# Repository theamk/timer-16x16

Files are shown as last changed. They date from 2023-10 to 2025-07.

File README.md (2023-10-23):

Timer with 16x16 dot display
----------------------------

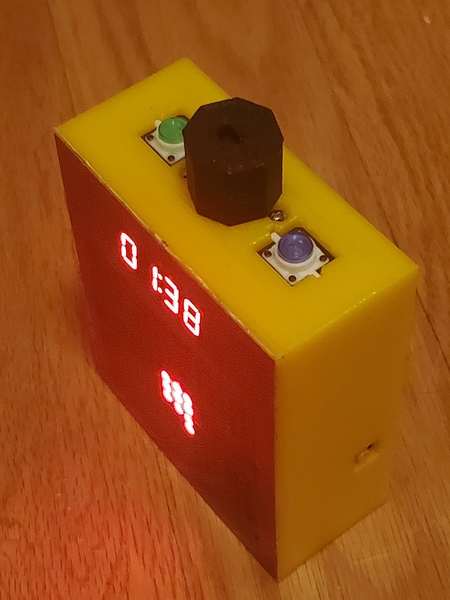
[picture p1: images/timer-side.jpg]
side view


Parts used
----------

The links are to aliexpress and things often disappear there.. so you might need to shop based on the pictures.
Also, I mostly used parts I had on hand already, hence so many different sellers. If buying all the parts for
this project, get similar looking ones from one seller.

- Raspberry PI PICO (non-W version,
  get one from your [local hardware store](https://www.microcenter.com/product/661033/raspberry-pi-pico-microcontroller-development-board))
- 4x 8x8 dot displays, based on MAX7219 chipset. You want the ones which can be stacked next to each other, with no protruding parts.
  I used red ones from my parts box. [Those](https://www.aliexpress.us/item/3256805799080954.html) look the same.
- 1x 0.36" 4-digit LED indicator, driven by TM1637. I used red one from my parts box, but it looks like 
  [this one](https://www.aliexpress.us/item/3256804119383891.html).
    - Had to desolder headers and attach wires directly instead.
- Input panel:
    - 2x buttons with LEDs (blue and green), "12x12" type ([those](https://www.aliexpress.us/item/2255799843768811.html)) 
    - Rotary encoder from my parts box.
    - Small piece of PCB to mount this all on. I've had [2x8cm proto PCB](https://www.aliexpress.us/item/3256804759687459.html) I've cut in half.
    - Pull-up resistors (I found 10x 2.2K resistor array in my toolbox)
- 3d-printed case, see [3dprint/] directory.
    - There are 3 parts: main body, holder for displays (goes between PCB and display itself) and encoder knob.
- Protoboard PCB, 70x90 mm ([this one](https://www.aliexpress.us/item/2251832485396886.html), but others would work too. 
  Note the dimensions vary a bit, especially in hole placement. You might need to tweak 3D model for your speciic board).
- 3D printed case
- Some colored film to cover the front - this is supposed to increase contrast. 
  I had red film in my parts box, no idea where I got it from)
- Optional: speaker
    - Small speaker (piezo or 4-ohm one)
    - almost any transistor (I had 2N222 in my parts box)
    - a resistor for that transistor
- Optional: battery setup (see below for details)

Schematics
----------

Sorry, never made a schematics. There is a PCB which serves as a back cover and as a mechanical
support, but most wiring is point-to-point. Here is a pinout:
```
Pinout:
  (left side)
  GP0
  GP1

  GP2
  GP3
  GP4
  GP5

  GP6   O - speaker (active high, via 2N2222 transistor)
  GP7
  GP8  IO - POSSIBLE EXPANSION: IMU SDA  (w/2.2K pull-up)
  GP9  IO - POSSIBLE EXPANSION: IMU SCL  (w/2.2K pull-up)

  GP10  I - encoder A (w/2.2K pull-up)
  GP11  I - encoder B (w/2.2K pull-up)
  GP12  I - button green (w/2.2K pull-up)
  GP13  I - button blue (w/2.2K pull-up)

  GP14  O - LED green (270 ohm to GND, active high)
  GP15  O - LED blue (270 ohm to GND, active high)

  (right side)
  GP16  I - SPI RX (unused)
  GP17  O - SPI CSn to MAX7219 8x8 displays

  GP18  O - SPI SCK to MAX7219 8x8 displays
  GP19  O - SPI TX to MAX7219 8x8 displays
  GP20  O - DATA to TM1637
  GP21  O - CLK to TM1637

  GP22  O - set high to force power off
  GP23  I - on-board voltage regulator mode selector
  GP24  I - on-board USB voltage sensor
  GP25  O - on-board LED

  GP26
  GP27
  GP28
```

PCB, mostly point-to-point wiring, the only moderately complex system is power

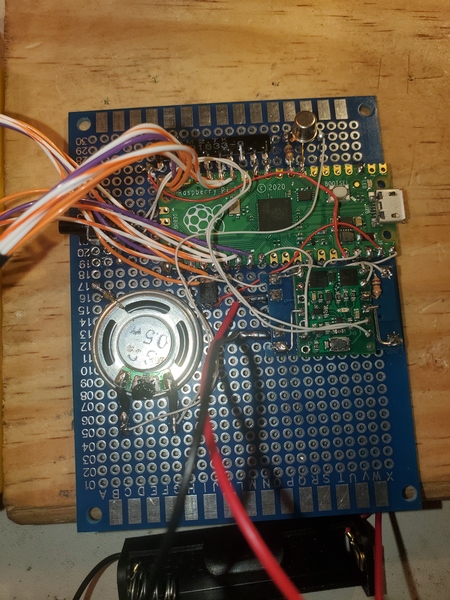
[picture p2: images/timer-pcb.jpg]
PCB (rear cover) view


The other side - enclosure with buttons and LEDs

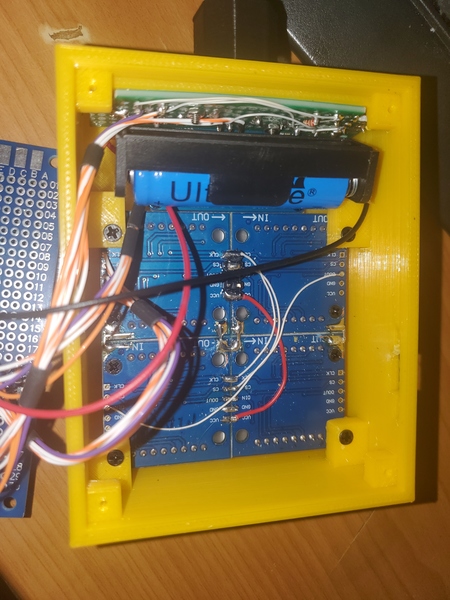
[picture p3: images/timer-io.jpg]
LED + buttons view


Mechanical assembly
-------------------

See 3d-printed case, see [3dprint/] directory.
There are 3 parts: main body, holder for displays (goes between PCB and display itself) and encoder knob.

For 8x8 displays, I've used some thick wires to solder the groundplanes together, making a single 16x16 panel. 
This turned out to be not the best idea in retrospect - I've got flatness wrong so you can see (and feel) boundaries 
between modules. A better idea would be to 3D print holders and mount each one using default mounting holes.

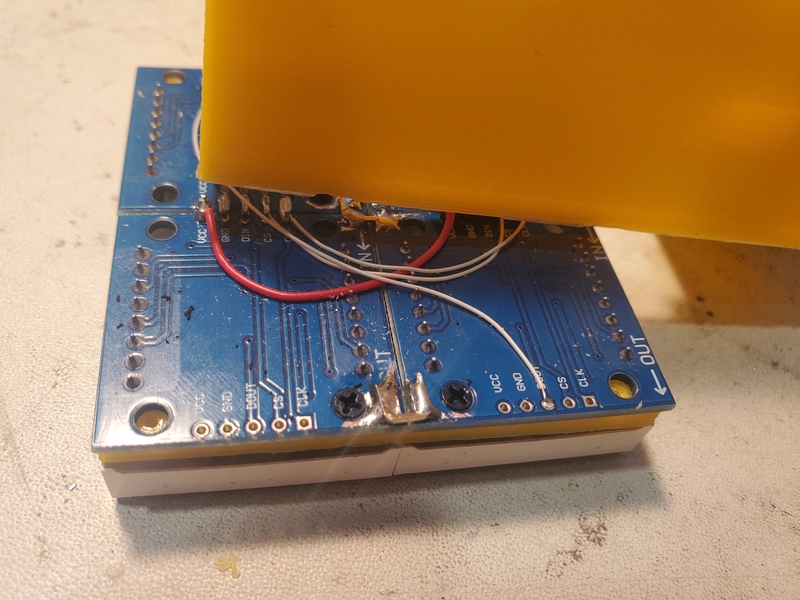
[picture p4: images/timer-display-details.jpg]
mounting displays


Power control
-------------

For simpler design, feel free to skip. Connect Vin pins of display to 
pico's VSYS, and you have a USB-powered device.

Or get [Pimoroni's lipo SHIM](https://shop.pimoroni.com/products/pico-lipo-shim?variant=32369543086163), 
I have not tried it but specs look good.. seems like it basically does all I do here in one tiny board.
Just needs a transistor across the power button to allow soft power off (and a very minor case redesign,
as "USB" and "Power" would be just one hole now).

I wanted rechargable battery, so I went with:

- Battery itself: AA holder + 14500 3.7V Li-ion battery
    - Be wary of that a lot 14500 Li-ion batteries are apparently very low quality - one I got had 130 mAh capacity instead of rated 1800 mAh.
    - Alternatively, 18650 with tabs might fit and be both cheaper and more powerful
- Battery charger board (
    [Micro USB 5V 1A 18650 TP4056 Lithium Battery Charger Module Charging Board With Protection](https://www.aliexpress.us/item/2251832640561273.html))
- Power switch board (to enable soft power off). I used [Pololu Mini Pushbutton Power Switch](https://www.pololu.com/product/2808)
    - This turned out to be too easy to turn off by accident. I wonder if [Sparkfun's Soft Power Switch](https://www.sparkfun.com/products/17870),
      which requires power button to be held for a long time to turn off, would work better?
        - It would also allow eliminating separate power button entirely, allowing one of the two big buttons on top to act as power switch.
- Power on/off button (right-angle tactile switch)

Charger/protection board is generic TP4056 model
It came with 1A charge current, but I modified it to ~500mA current:
The current is set by resistor labeled R3.
The stock R3 was 122, which is 1.2K, which is ~1A.
I replaced it with 2201, which means 2.2K, which gave me ~0.56A limit.

Note that LEDs draw directly from battery, so the actual charging current is less
when display is on. Current use:

- pixels brightness 1: 80 to 240 mA, depending on # of pixeles lit
- pixels brightness 7: not measured, probably too bright

The overall schematics is somewhat complicated, because Pico and LEDs
have different power paths. This was because of requirements:

1. When powering from battery, give as much voltage to LEDs as possible, 
avoiding any diode drops (they are officially rated for 5V only after all, and I am powering
them from 3.6V lithium battery.. let's not make it worse).
2. Fully support operation when powered from pico's USB port.
3. Have "soft" power switch, with recessed button and software-controlled power-off. It should
   work even over USB.

```
 PICO:VBUS               GND
   |                      |
[ VIN+                   VIN- ]
[                             ]
[ charger / protection board  ]
[ (upside-down to expose LED) ]
[ modded to decrease Icharge  ]
[                             ]
[  OUT+ BATT+    BATT-  OUT-  ]
    |    |         |     |
    |    \- 14300 -/    GND
    |
    |              /-PICO:GP22
  /---\   /-GND-\  |  x   x
  |   |   |     |  |  |   |
[ IN+ IN+ GND GND ON OFF CTRL ]
[                             ]
[  POLOLU mini pushshbutton   ]
[   power switch (LV 2808)    ]
[                             ]
[ OUT OUT GND GND  SW-A  SW-B ]
   |   |  |     |    |     |
   \-|-/  \-GND-/    \-BTN-/    <- power button (outside)
     |
     +---PICO:3V3_EN   (so switch works even for USB input)
     +--[R:10K]--GND   (making sure 3V3_EN is pulled down with output is off)
     +--Vcc of LED displays
     |
     \--|>|--PICO:VSYS (use any diode, PI has regulator that'll step voltage up if needed)
```

Firmware
--------

1. Install [platformio](https://platformio.org/install). I use "core" version which is a simple command line tool.

2. Power up the device and plug in USB cable

3. `pio run -t upload`

4. If building for the very first time, it may fail because there is no bootloader in the image. In this case:

    - Power up/plug in device while holding "prog" button on the Pico board
    - Your computer should detect an removable disk dialog
    - The "pio run" error message should have mentioned an UF2 file location..
       Usually something like `.pio/build/pico/firmware.uf2`.
    - Copy this file to external disk. Device will auto-reboot into new firmware.
    - This only needs to be done once, once firmware is in place regular upload should just work..

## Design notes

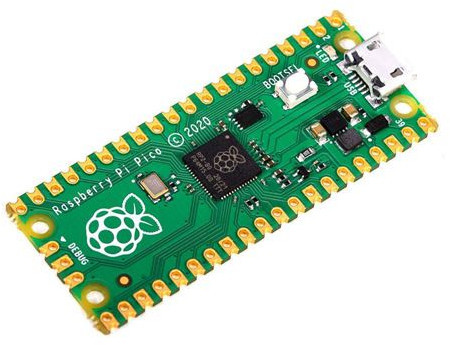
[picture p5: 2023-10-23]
images/pi-pico.jpg

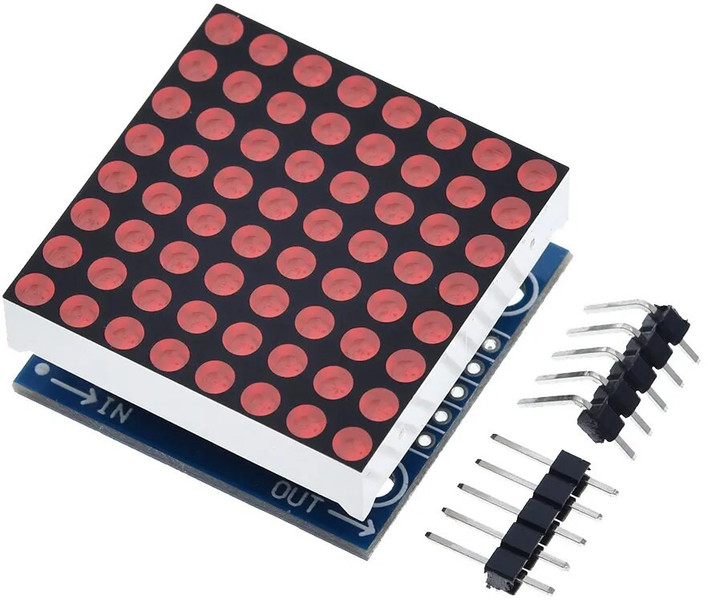
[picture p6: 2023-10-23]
images/display-8x8.jpg

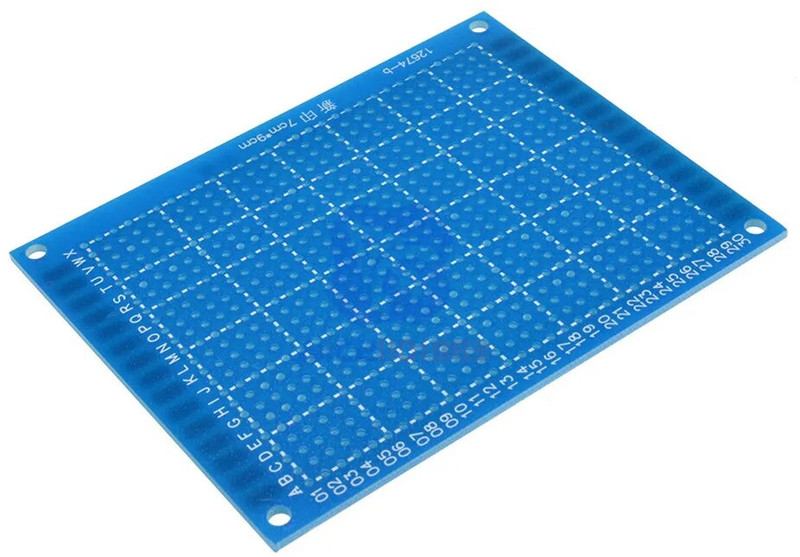
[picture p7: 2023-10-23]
images/PCB-7x9.jpg

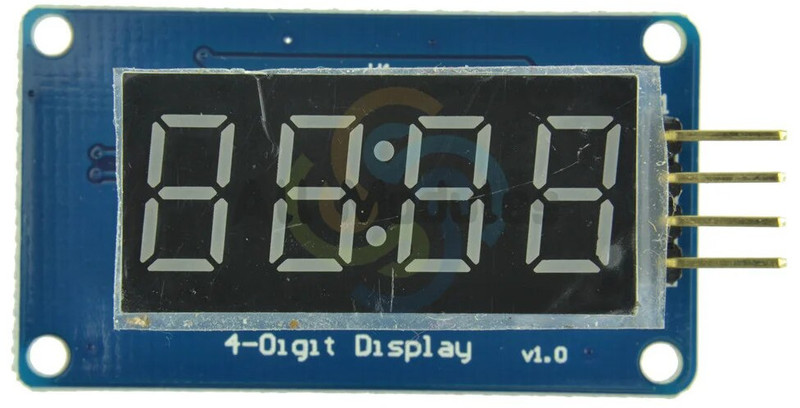
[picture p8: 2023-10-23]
images/display-7seg.jpg

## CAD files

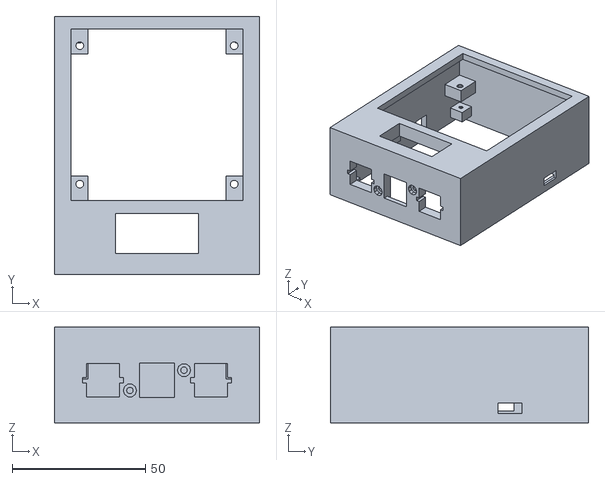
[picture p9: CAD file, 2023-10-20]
3dprint/timer16x16box.stl
77.0 x 97.0 x 36.0

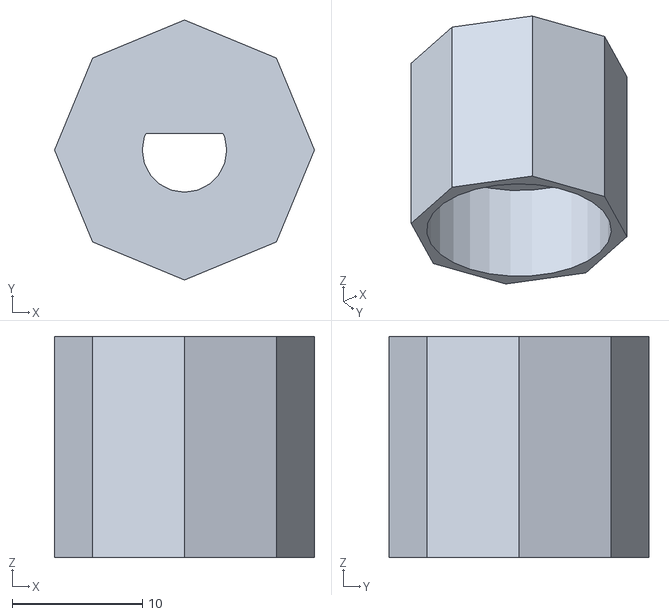
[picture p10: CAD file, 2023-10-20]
3dprint/knob-d-shaft-1.stl
20.0 x 20.0 x 17.0

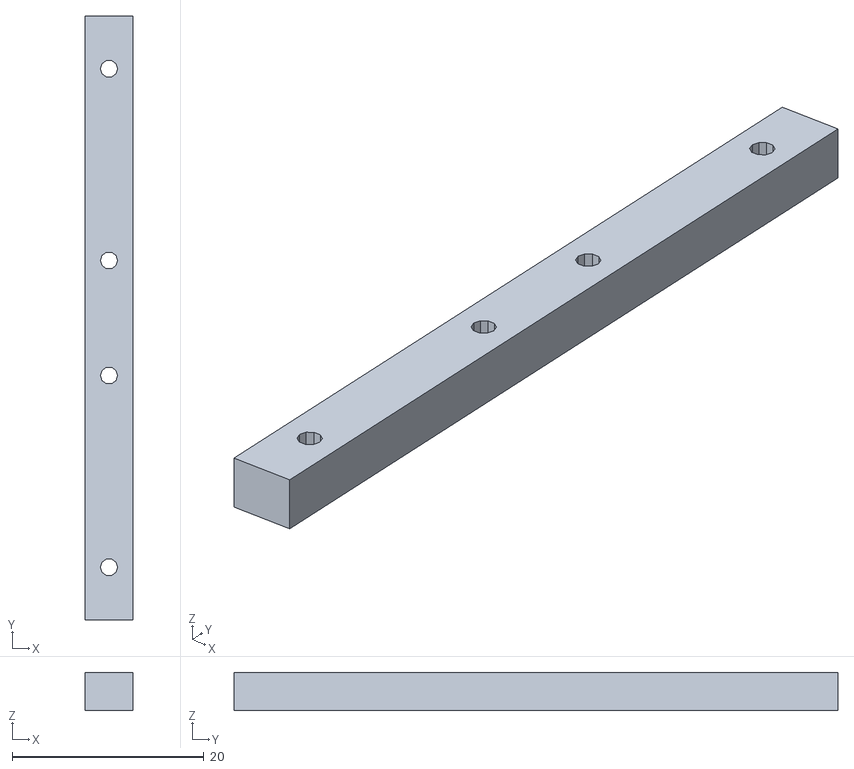
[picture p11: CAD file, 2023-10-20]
3dprint/timer16x16holder.stl
5.00 x 63.0 x 4.00

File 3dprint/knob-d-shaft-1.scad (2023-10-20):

// a knob for unnamed encoder
// with D-shaped 6 mm shaft

SHAFT_D = 6 + 0.5; // diameter
// height of part at the end with flat
SHAFT_CUTOUT_HEIGHT = 8; 
// flat diameter (to ther end of shaft, as measured by calipers)
SHAFT_CUTOUT_DEPTH = 4.5; 

KNOB_D = 20;
KNOB_INNER_D = 17; // hide encoder body
KNOB_HEIGHT = 17; // including TOP_WALL

TOP_WALL = -0.1; 

difference() {
    // knob body, intentionally non-circular
    cylinder(d=KNOB_D, h=KNOB_HEIGHT, $fn=8);
    
    // at the bottom, there is a wide cutout
    translate([0, 0, -0.1])
    cylinder(d=KNOB_INNER_D, h=KNOB_HEIGHT - SHAFT_CUTOUT_HEIGHT - TOP_WALL + 0.1);
    
    difference() {
        // shaft hole
        cylinder(d=SHAFT_D, h=KNOB_HEIGHT - TOP_WALL, $fn=20);
        
        // "D" cutout
        translate([-10, SHAFT_CUTOUT_DEPTH - SHAFT_D/2, 0])
        cube([20, 20, 40]);
    }
}

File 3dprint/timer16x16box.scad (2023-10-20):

// box for 16x16 timer
//  top side (closed) is where displays are
//  bottom side is closed with lid, made out of PCB

// rev 2 ("yellow") comments:
//  - Printed with 10mm brim, "high detail" mode. This was very slow,
//    but came out great.
//  - 256PX hole supports were so thick I had to switch to 12mm screws
//    which I only have in 2.6 mm dia.. so had to drill out the holes
//  - power button hole wrong (too tall) - not a real problem
//  - USB hole wrong (shifted by 1mm) - had to file it
//  - both power button and USB connection stick out of board.. so any time
//    board is installed/removed, there is a pressure on power button. 
//    It works so far, but I suspect button might fail eventually
//  - 7-segment display was a bit tricky to install due to control board
//    extra base overhanging.. but managed eventually. Maybe shorten
//    that extra base a bit.
//  - cutting corners of controls board was a pain. Maybe reduce size of PCB
//    mounting block?

WALL = 3;

// "Lip" on top, to conceal sides of red film
// walls are reduced thickness, as they are not structural
// NOTE: lip sounded like a great idea but my printer can't print it
// at h=1. So setting it to almost 0 to disable
LIP_HEIGHT = 0.001; 
LIP_WALL = 3;

// bottom lip height. walls are full thickness
// (this is offset from PCB mounting blocks to bottom of the box,
// if this is = to PCB thickness, the bottom would be even)
BOTTOM_LIP_HEIGHT = 3;

// inner X/Y is defined by PCB size, which is used as a bottom cover
INNER_X = 70 + 1; // don't forget some slop
INNER_Y = 90 + 1;
INNER_Z = 30;

// PCB mounting block hole offset from board edge
PCB_HOLE_X1 = 3.5;
PCB_HOLE_X2 = 2.5;
PCB_HOLE_Y = 3.5;
PCB_BLOCK_Z = 5;  // mounting block Z thickness
PCB_BLOCK_XY = 7; // mounting block X/Y extra 

// 7-segment (for time)
// mounting PCB is non-symmetric, but we don't bother to mode it fully,
// and instead increase sizes so that both sides fit, assuming display is centered
// (real one is smaller on one side)
PCB_Y_7SEG = 25; // height of PCB, _if_ it were symmetric
PCB_X_7SEG = 45; // width of PCB, _if_ it were symmetric
// center Y, Z offset
OFFSET_Y_7SEG = PCB_Y_7SEG / 2 - 0.1;
// top of PCB to top of display
HEIGHT_7SEG = 7.5;

// no overlap with Y- wall (except tiny one to avoid rounding errors)
assert((OFFSET_Y_7SEG - PCB_Y_7SEG/2) >= -0.1);

// 16x16 module, made out of quad 8x8
SIZE_256PX = 64; // module is square
SLOP_256PX = 0.5; // evenly spread across both sizes
THICKNESS_256PX = 13.5; // front panel to back of PCB
OFFSET_Y_256PX = INNER_Y - SIZE_256PX / 2 - 2; // Y of centerpoint of display
MNT_256PX_X_OFFS = 3; // hole offset X, from side
MNT_256PX_Y_OFFS = 6; // hole offset Y, from side
MNT_256PX_SIZE = 6;  // Y axis is twice as much

// overlap with 7-segment display is not too big (small one is OK)
assert((OFFSET_Y_7SEG + PCB_Y_7SEG/2 - 8) <= 
       (OFFSET_Y_256PX - SIZE_256PX/2));

CONTROLS_CENTER_Z = INNER_Z / 2 + 2; // slightly shifted to front
       
// Charger hole, size - need to fit "most" usb cables,
// and there is a power switch underneath too
CHARGER_HOLE_SIZE_Y = 9;
CHARGER_HOLE_SIZE_Z = 4;
CHARGER_HOLE_PCB_Y = 21;
CHARGER_HOLE_PCB_Z = 2;
// and center offset
CHARGER_HOLE_OFFSET_Y = 26.5; // PCB side to center of hole
CHARGER_HOLE_OFFSET_Z = 0.5; // PCB inner surface to bottomhole
       
// power switch - which is 7x7 button with right angle mount
POWER_HOLE_SIZE_Y = 8;
POWER_HOLE_SIZE_Z = 8;
// and center offset
POWER_HOLE_OFFSET_Y = 29; // PCB side to center of switch
POWER_HOLE_OFFSET_Z = 1.5; // PCB inner surface to bottom of button hole

/*
// battery box (which is a single AA holder with 14500 lipo inside)
// (bare battery: 53x14x14, holder: 59x17x17)
BBOX_SIZE_X = INNER_X + 0.1;
BBOX_SIZE_Y = 14;
BBOX_SIZE_Z = 14;
BBOX_WALL = 2;
*/
     
difference() {   
    // outer walls
    // Zmin = INNER_Z + BOTOMLIP_HEIGHT
    // Zmax = WALL + LIP_HEIGHT
    translate([-WALL, -WALL, -INNER_Z - BOTTOM_LIP_HEIGHT])
    cube([INNER_X + 2*WALL, INNER_Y + 2*WALL, 
          INNER_Z + WALL + BOTTOM_LIP_HEIGHT + LIP_HEIGHT]);
    
    difference() {
        // main volume for PCB
        translate([0, 0, -(INNER_Z + 100) - 0.1])
        cube([INNER_X, INNER_Y, INNER_Z + 100]);
        
        // extra base for 7-segment digits
        translate([INNER_X / 2, OFFSET_Y_7SEG, 0])
        cube([PCB_X_7SEG, PCB_Y_7SEG, HEIGHT_7SEG], center=true);
        
        // extra base control buttons backplane 
        translate([INNER_X / 2 - 65/2, -0.1, -CONTROLS_CENTER_Z - 20/2])
        cube([65, 2, 20]);

        /*
        // battery box
        translate([INNER_X / 2 - BBOX_SIZE_X / 2 - BBOX_WALL, 
                   INNER_Y - BBOX_SIZE_Y - BBOX_WALL - 0.1,
                   -INNER_Z])
        cube([BBOX_SIZE_X + BBOX_WALL * 2, 
              BBOX_SIZE_Y + BBOX_WALL, 
              BBOX_SIZE_Z + BBOX_WALL]);
        */
    }

    /*
    // battery box cutout
    translate([INNER_X / 2 - BBOX_SIZE_X / 2, 
               INNER_Y - BBOX_SIZE_Y,
               -INNER_Z - 0.1])
    cube([BBOX_SIZE_X, BBOX_SIZE_Y, BBOX_SIZE_Z + 0.1]);
    */

    // Top lip cutout
    translate([LIP_WALL-WALL, LIP_WALL-WALL, WALL])
    cube([INNER_X - 2*(LIP_WALL-WALL), INNER_Y - 2*(LIP_WALL-WALL), 100]);
        
    // cutout for 256PX (16x16) display
    translate([INNER_X / 2, OFFSET_Y_256PX, 0])
    cube([SIZE_256PX + SLOP_256PX, SIZE_256PX + SLOP_256PX, THICKNESS_256PX],
         center=true);
    
    // cutout for 7-segment digits
    // (we don't bother with mouting holes, they are drilled in place)
    translate([INNER_X / 2, OFFSET_Y_7SEG, 0])
    cube([31, 15, 100], center=true);
    
    /*
    // cutout for encoder, 25LB10Q model
    translate([INNER_X / 2, 1, -INNER_Z / 2])
    rotate([90, 0, 0]) {
        cylinder(d=8.5, h=10);  // main shft
        // anti-rotatino hole
        translate([0, -10, 0]) cylinder(d=4, h=10);
        // body - a slight dip (note contacts are 2 more mm)        
        cube([22, 22, 4], center=true);        
    }
    */
    
    // cutout for encoder, unnamed PCB-mount model
    translate([INNER_X / 2, 1, -CONTROLS_CENTER_Z]) {
        // main body
        cube([13, 20, 13], center=true);
        // expand top/bottom side for contacts
        cube([13, 3.5, 17], center=true);
    }
    
    // cutout for control buttons
    for (ox=[-1, 1])
    translate([INNER_X / 2 + ox * 8 * 2.54, 1, -CONTROLS_CENTER_Z]) {
        cube([12.5, 10, 12.5], center=true);
        // extra for light connectors
        cube([15.5, 10, 2], center=true);
    }
    
    // holes for control panel mount
    for (ox=[-1, 1])
    translate([INNER_X / 2 + ox * 4 * 2.54, 
                1, 
                -CONTROLS_CENTER_Z + ox * 1.5 * 2.54])
        rotate([90, 0, 0]) {
        // hole
        cylinder(d=2.5, h=30, center=true, $fn=10);
        // concealed head
        translate([0, 0, WALL - 1])
        cylinder(d=5, h=10, $fn=10);
        }
            
           
    // cutout for power button - a latching, lighted model
    //translate([INNER_X * 0.75, INNER_Y - 1, -INNER_Z / 2])
    //rotate([-90, 0, 0])
    //cylinder(d=12, h=10);
    
    // port for USB connection
    translate([INNER_X - 1,
               INNER_Y - CHARGER_HOLE_OFFSET_Y - CHARGER_HOLE_SIZE_Y / 2, 
               -INNER_Z + CHARGER_HOLE_OFFSET_Z])
    cube([10, CHARGER_HOLE_SIZE_Y, CHARGER_HOLE_SIZE_Z]);
    
    // a small cutout for PCB that USB connector is mounted on
    translate([INNER_X - 0.1,
               INNER_Y - CHARGER_HOLE_OFFSET_Y - CHARGER_HOLE_PCB_Y / 2, 
               -INNER_Z])
    cube([WALL - 1, CHARGER_HOLE_PCB_Y, CHARGER_HOLE_PCB_Z]);
    
    translate([-10,
               INNER_Y - POWER_HOLE_OFFSET_Y - POWER_HOLE_SIZE_Y/2, 
               -INNER_Z + POWER_HOLE_OFFSET_Z])
    cube([20, POWER_HOLE_SIZE_Y, POWER_HOLE_SIZE_Z]);
}

// 256PX mounting blocks
mount_block_hole_x = (INNER_X - SIZE_256PX) / 2 + MNT_256PX_X_OFFS;
for (ox=[-1, 1]) for (oy=[-1, 1])
    translate([INNER_X/2 - ox * INNER_X / 2, 
               oy * (SIZE_256PX - 2*MNT_256PX_Y_OFFS) / 2 + OFFSET_Y_256PX, 
               -THICKNESS_256PX - WALL])
    scale([ox, oy, 1])
    difference() {
        translate([-0.1, 
                   -(MNT_256PX_SIZE + 0.2)/2, 
                   0])
        cube([mount_block_hole_x + MNT_256PX_SIZE / 2 + 0.1, 
              2 * MNT_256PX_SIZE+0.2, 
              MNT_256PX_SIZE]);
        
        translate([mount_block_hole_x, 0, -1])
        cylinder(d=3, h=30, $fn=10);
}
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

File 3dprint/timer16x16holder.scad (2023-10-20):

// a holder to mount256px display
// print 2 of those, insert between display and PCB
// works together with "timer16x16box" model


// from timer16x16box.scad
SIZE_256PX = 64; // module is square
MNT_256PX_Y_OFFS = 6; // hole offset Y, from side

// defined here
SLOP = 1;
WIDTH = 5;
THICKNESS = 4;

difference() {
    cube([WIDTH, SIZE_256PX - SLOP, THICKNESS], center=true);
    for (oy=[-1, 1]) 
      scale([1, oy, 1]) {
        // two holes in the middle are attaching holder to display
        // they are for making install easier only
        translate([0, MNT_256PX_Y_OFFS, 0])
        cylinder(d=1.8, h=10, center=true, $fn=10);
        
        // two holes in the sides are important ones, they accept
        // mounting screws
        translate([0, SIZE_256PX/2 - MNT_256PX_Y_OFFS, 0])
        cylinder(d=1.8, h=10, center=true, $fn=10);
    }
}    

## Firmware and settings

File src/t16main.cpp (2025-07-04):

/*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
You should have received a copy of the GNU General Public License along with
this program. If not, see <https://www.gnu.org/licenses/>.
*/
#include <Arduino.h>

#include <stdlib.h>
//#include <pico/rand.h>
#include <include/lwipstack/lwipopts.h>

#include <RP2040_PWM.h>
#include "TM1637.h"
#include <pio_encoder.h>

#include "display_driver.h"

/*

Future hardware:
   accelerometer
*/

void set_random_pixels(int count);

#define CLOCK_CLK    21
#define CLOCK_DIO    20
TM1637 clock_disp(CLOCK_CLK, CLOCK_DIO);


#define PIN_LED_GREEN   15
#define PIN_LED_BLUE    14
#define PIN_BTN_GREEN   13
#define PIN_BTN_BLUE    12

#define PIN_ENCODER_A   10
#define PIN_ENCODER_B   11

#define PIN_POWER_OFF   22

#define PIN_SPEAKER     6

// how long to spend in settings mode with no input before switching off
#define IDLE_POWER_OFF_INTERVAL  (10 * 60 * 1000)

// How many ms of shaking does each encoder turn add?
#define SHAKE_MS_PER_ENCODER_TICK    100
// What's the maximum wind-up?
#define SHAKE_MS_MAX_VALUE           3000
// How many MS per shake state (on ouptut)
#define SHAKE_MS_PER_STATE           50

PioEncoder encoder(PIN_ENCODER_A);  // B must be A + 1
RP2040_PWM * speaker;

unsigned long power_off_time = 0;
int shake_amount_ms = 0;

void setup() {
  pinMode(LED_BUILTIN, OUTPUT);

  pinMode(PIN_LED_GREEN, OUTPUT);
  pinMode(PIN_LED_BLUE, OUTPUT);

  encoder.begin();

  clock_disp.begin();
  clock_disp.clearScreen();

  display_init();

  srand(lwip_get_random());

  speaker = new RP2040_PWM(PIN_SPEAKER, 1000, 0);

  //set_random_pixels(60);

}

void set_random_pixels(int count) {
  if (count > 255) { count = 255; };
  display_set_all(false);
  while (count > 0) {
    int x = random() % DISP_WIDTH;
    int y = random() % DISP_HEIGHT;
    if (!display_setpixel(x, y, true)) { count--; };
  }

  display_update();
}

void set_spiral_pixels(int count, int shake=0) {
  display_set_all(false);
  int x=0, y=0;
  int dx=0, dy=-1;
  int shake_x=0, shake_y=0;

  static const int shake_offsets[8][2] = {
    {-1, 1}, {0, 1}, {1, 1}, {1, 0},  {1, -1}, {0, -1}, {-1, -1}, {-1, 0},  //{-1, 1}
  };
  if (shake > 0) {
    // Since shaking lasts for a short time, we make no attempt to compensate when many LEDs are lit
    // total number of lit leds might be <count if shake is nonzero
    int mult  = ((shake - 1)) / 32 + 1;
    int phase = ((shake - 1)) % 8;
    shake_x = shake_offsets[phase][0] * mult;
    shake_y = shake_offsets[phase][1] * mult;
  }

  while (count > 0) {
    display_setpixel(x + 7 + shake_x, y + 7 + shake_y, true);
    if ((x == y) || (x < 0 && x == -y) || (x > 0 && x == 1 - y)) {
      int temp = dx;
      dx = -dy;
      dy = temp;
    }
    x += dx; y += dy;
    count--;
  }
  display_update();
}


int last_speaker_freq = -1;
void set_speaker_freq(int freq) {
  if (last_speaker_freq == freq) {
    return;
  }
  if (freq == 0) {
    speaker->setPWM(PIN_SPEAKER, 1000, 0);
  } else {
    // very low duty cycle.. "10" (10%) is enough to be pretty loud.
    speaker->setPWM(PIN_SPEAKER, freq, 5);
  }
  last_speaker_freq = freq;
}


enum {
  T_TICK_UP,
  T_TICK_DOWN,
  T_EXPIRED,
  T_SET_TIME,
} timer_mode = T_SET_TIME;

enum {
  M_EXIT,     // default, exit menu
  M_SET_STEP, // set time interval
  // set end tone
  // set display type (spiral/random/etc...)
  M_MAX_VALUE = M_SET_STEP,
} menu_item = M_EXIT;
bool menu_active = false;

// timer value, seconds
int time_left = 0;
// millis() timestamp when this changes
unsigned long next_tick = 0;
// how many seconds does each pixel represent
int pixel_time = 10;


unsigned long tone_state = 0;
void maybe_update_speaker() {
  if (!tone_state) {
    set_speaker_freq(0);
  } else { // play the tone
    unsigned int elapsed = millis() - tone_state;
    static int melody[] = {
      523, 523, 587, 523, 698, 659,
    };

    if ((elapsed % 300) < 50) { set_speaker_freq(0); }
    else {
      unsigned int num = elapsed / 300;
      if (num < (sizeof(melody)/sizeof(melody[0]))) {
	set_speaker_freq(melody[num]);
      } else {
	tone_state = 0;
	set_speaker_freq(0);
      };
    }
  }
}


void handle_buttons() {
  // debounce green
  static unsigned long green_down_since = 0;
  bool green_down = false;
  if (digitalRead(PIN_BTN_GREEN)) {
    green_down_since = 0;
  } else if (!green_down_since) {
    green_down_since = millis();
  } else if (millis() > (green_down_since + 50)) {
    green_down = true;
  }

  static unsigned long blue_down_since = 0;
  bool blue_down = false;
  if (digitalRead(PIN_BTN_BLUE)) {
    blue_down_since = 0;
  } else if (!blue_down_since) {
    blue_down_since = millis();
  } else if (millis() > (blue_down_since + 50)) {
    blue_down = true;
  }

  static bool green_was_down = false;
  if (green_down && !green_was_down) {
    // green button controls timer mode
    if (menu_active) {
      // exit menu
      menu_active = false;
    } else switch(timer_mode) {
      case T_EXPIRED:
      case T_TICK_UP:
      case T_TICK_DOWN: // was ticking -> pause, set time
	timer_mode = T_SET_TIME;
	break;
      case T_SET_TIME:
	if (time_left == 0) {
	  timer_mode = T_TICK_UP;
	} else {
	  timer_mode = T_TICK_DOWN;
	}
	next_tick = millis();
	break;
      }
  };
  green_was_down = green_down;

  static bool blue_was_down = false;
  if (blue_down && !blue_was_down) {
    // blue button enters menu, then executes menu item
    if (!menu_active) {
      // enter menu
      menu_active = true;
    } else switch (menu_item) {
      case M_EXIT:
	menu_active = false;
	break;
      case M_SET_STEP:
	// TODO
	break;
    }
  };
  blue_was_down = blue_down;

  if (green_down || blue_down) {
    power_off_time = 0; // any input resets power-off timer
    tone_state = 0; // any input turns tone off
  }
}


void handle_encoder() {
  // our encoder gives us 4 counts per detent
  int this_encoder = encoder.getCount() / 4;
  static int last_encoder = 0;
  int delta_encoder = this_encoder - last_encoder;
  last_encoder = this_encoder;

  if (delta_encoder == 0) {
    return;
  }
  power_off_time = 0;
  tone_state = 0; // any input turns tone off

  if (menu_active) {
    (int&)menu_item = ((int)menu_item + delta_encoder + M_MAX_VALUE + 1) % (M_MAX_VALUE + 1);
  } else if (timer_mode == T_SET_TIME) {
    // when pixels are small, always do one step == one pixel. But when they are large, provide finer steps.
    int scroll_step = (pixel_time < 60) ? pixel_time :
      (time_left >= 600) ? 60 : 15;
    while (delta_encoder < 0) {
      delta_encoder++;
      time_left = ((time_left - 1) / scroll_step) * scroll_step;
      if (time_left < 0) { time_left = 0; }
    }
    while (delta_encoder > 0) {
      delta_encoder--;
      time_left = ((time_left / scroll_step) + 1) * scroll_step;
    }
  } else {
    // shake it!
    shake_amount_ms += SHAKE_MS_PER_ENCODER_TICK * delta_encoder;
    if (shake_amount_ms > SHAKE_MS_MAX_VALUE) { shake_amount_ms = SHAKE_MS_MAX_VALUE; }
    if (shake_amount_ms < -SHAKE_MS_MAX_VALUE) { shake_amount_ms = -SHAKE_MS_MAX_VALUE; }
  }
}


void update_leds() {
  unsigned long partial = (millis() + 2000 - next_tick) % 1000;
  switch (timer_mode) {
  case T_TICK_UP:
  case T_TICK_DOWN:
    digitalWrite(PIN_LED_GREEN, partial < 100); // blink  once per second
    break;
  case T_EXPIRED:
    digitalWrite(PIN_LED_GREEN, (partial % 250) < 125); // blink quickly nonstop
    break;
  case T_SET_TIME:
    digitalWrite(PIN_LED_GREEN, true);
  }

  digitalWrite(PIN_LED_BLUE, menu_active);
}


void update_maybe_power_off() {
  if (timer_mode == T_TICK_UP || timer_mode == T_TICK_DOWN) {
    // if timer is ticking or inputs, don't power off
    power_off_time = 0;
  } else if (!power_off_time) {
    // activity happened, reset timer
    power_off_time = millis() + IDLE_POWER_OFF_INTERVAL;
  } else if (power_off_time < millis()) {
    // power off time
    digitalWrite(PIN_POWER_OFF, 1);
    // should not reach here, but in case it didn't work for some reason, reset.
    delay(100);
    digitalWrite(PIN_POWER_OFF, 0);
    power_off_time = 0;
  }
}


#include "generated_images.inc"

const int kPixelTimeOptions[] = { 10, 15, 30, 60, 120 };
#define kPixelTimeOptionCount (sizeof(kPixelTimeOptions)/sizeof(kPixelTimeOptions[0]))

void maybe_refresh_256px_display() {
  uint16_t* icon = NULL;

  if (menu_active) {
    switch (menu_item) {
    case M_EXIT:
      static_assert(MiscIcons_COUNT > 0);
      icon = MiscIcons[0];
      break;
    case M_SET_STEP:
      static_assert(StepSet_COUNT == kPixelTimeOptionCount);
      for (int i=0; i<StepSet_COUNT; i++) {
	if (kPixelTimeOptions[i] == pixel_time) {
	  icon = StepSet[i];
	  break;
	}
      }
      if (!icon) {
	// error/undefined value -> blink two options to indicate this
	icon = ((millis() / 100) % 2) ? StepSet[0] : StepSet[StepSet_COUNT-1];
      }
      break;
    }
  }
  
  static uint16_t* last_icon = nullptr;
  static int last_pixels = -1, last_shake_state = -1;

  if (icon) {
    if (icon != last_icon) {
      display_show_icon(icon);
      display_update();
      last_icon = icon;
    }
    last_pixels = -1;
    return;
  }
  last_icon = nullptr;

  int pixels = (time_left + pixel_time - 1) / pixel_time;

  if (timer_mode == T_TICK_DOWN && ((time_left % pixel_time) == 1)) {
    // last pixel blinks before disappearing
    unsigned long partial = 1000 - (millis() + 2000 - next_tick) % 1000;
    if ((partial > 50 && partial < 100) ||
	(partial > 150 && partial < 200)) {
      pixels--;
    }
  };

  int shake_state = abs(shake_amount_ms) / SHAKE_MS_PER_STATE;

  if (pixels != last_pixels || shake_state != last_shake_state) {
    set_spiral_pixels(pixels, shake_state);
    last_pixels = pixels;
    last_shake_state = shake_state;
  };
}

void maybe_refresh_7seg_display() {
  char buff[20] = {};
  if (time_left < 3600) {
    // less than 1 hour -> show minutes + seconds, 2 digits
    sprintf(buff, "%02d%02d", (time_left / 60), (time_left % 60));
  } else {
    // more than 1 hour -> show hours + minutes, 1 digit
    sprintf(buff, "%2d%02d", (time_left / 3600), ((time_left / 60)% 60));
  }
  if (timer_mode == T_SET_TIME && power_off_time) {
    // blink on idle input
    unsigned long idle = (millis()  + IDLE_POWER_OFF_INTERVAL - power_off_time );
    if ((idle > 500) & ((idle % 500) > 250)) {
      sprintf(buff, "      ");
    }
  }
  bool colon = (timer_mode != T_TICK_UP) || (timer_mode != T_TICK_DOWN) || (time_left & 1);

  // Force change invisible character because there is a bug: display won't refresh if
  // only colon changes but string stays the same.
  buff[4] = colon ? ':' : ' ';
  buff[5] = 0;

  static String last_display = "ZZZZZZ";
  if (last_display == buff) {
    return;
  }
  last_display = String(buff);

  // Re-enable pins if they were disabled before (see below)
  pinMode(CLOCK_DIO, OUTPUT);
  pinMode(CLOCK_CLK, OUTPUT);
  delay(1);

  clock_disp.setBrightness(7); // 0..7
  if (colon) {
    clock_disp.colonOn();
  } else {
      clock_disp.colonOff();
  }
  clock_disp.display(last_display);

  // We want to tri-state control pins between runs, to enable soft shut-off
  // the TM1637 library we have uses "mI2C.h" driver, which uses regular digitalWrite
  // calls. So we can just tri-state the pins.
  pinMode(CLOCK_CLK, INPUT_PULLUP);
  pinMode(CLOCK_DIO, INPUT);
}


void loop() {
  handle_buttons();
  handle_encoder();

  update_leds();
  maybe_update_speaker();

  unsigned long now = millis();
  static unsigned long prev_now;
  if (shake_amount_ms > 0) {
    shake_amount_ms = max(0, shake_amount_ms - (int)(now - prev_now));
  } else if (shake_amount_ms < 0) {
    shake_amount_ms = min(0, shake_amount_ms + (int)(now - prev_now));
  }
  prev_now = now;

  // tick handling
  switch (timer_mode) {
  case T_SET_TIME:
  case T_EXPIRED:
    break;
  case T_TICK_UP:
  case T_TICK_DOWN:
    if (next_tick < millis()) {
      next_tick += 1000;
      if (timer_mode == T_TICK_UP) {
	time_left++;
      } else {
	time_left--;
	if (time_left == 0) {
	  timer_mode = T_EXPIRED;
	  tone_state = millis(); // start music playback
	}
      }
    }
    break;
  }

  update_maybe_power_off();

  maybe_refresh_7seg_display();
  maybe_refresh_256px_display();
}

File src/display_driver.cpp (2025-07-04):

#include <display_driver.h>
#include <Arduino.h>

#include <SPI.h>

SPISettings display_settings(100000, MSBFIRST, SPI_MODE0);
#define SPI1_MISO 16  // not used
#define SPI1_MOSI 19
#define SPI1_SCLK 18
#define SPI1_CS_DISP 17
//arduino::MbedSPI SPI1(SPI1_MISO, SPI1_MOSI, SPI1_SCLK);

static void display_send_raw(uint8_t cmd, uint8_t data[4]) {
  digitalWrite(SPI1_CS_DISP, 0);
  SPI.beginTransaction(display_settings);
  delay(1);
  SPI.transfer(cmd); SPI.transfer(data[0]);
  SPI.transfer(cmd); SPI.transfer(data[1]);
  SPI.transfer(cmd); SPI.transfer(data[2]);
  SPI.transfer(cmd); SPI.transfer(data[3]);
  delay(1);
  SPI.endTransaction();
  digitalWrite(SPI1_CS_DISP, 1);
}

static void display_send_raw_all(uint16_t cmddata) {
  uint8_t d = cmddata & 0xFF;
  uint8_t data[4] = {d, d, d, d};
  display_send_raw(cmddata >> 8, data);
}

uint8_t framebuffer[32] = {0};

void display_update() {
  // To enable soft power-off, we tristate pins when unused. So enable them back.
  pinMode(SPI1_CS_DISP, OUTPUT);
  digitalWrite(SPI1_CS_DISP, 1);
  SPI.begin();
  delay(1);

  // docs:
  // https://www.analog.com/media/en/technical-documentation/data-sheets/MAX7219-MAX7221.pdf

  // lines were tri-stated, so send some no-ops to avoid glitches
  display_send_raw_all(0);

  // Start by setting framebuffer to the right value
  for (int i=0; i<8; i++) {
    display_send_raw(0x01 + i, &framebuffer[i*4]);
  }
  display_send_raw_all(0x0900); // no decode, confirms default
  display_send_raw_all(0x0A01); // intensity in last digit, 0..0xF
  display_send_raw_all(0x0B07); // display full 8x8, confirms default
  display_send_raw_all(0x0F00); // display test off, confirms default
  display_send_raw_all(0x0C01); // take displays out of shutdown

  // Another no-op for the road, in case tri-stated lines get loaded somehow.
  display_send_raw_all(0);

  // Now that we are done, turn things off again
  SPI.end();
  pinMode(SPI1_CS_DISP, INPUT_PULLUP);
  pinMode(SPI1_MOSI, INPUT);
  pinMode(SPI1_SCLK, INPUT);
}

bool display_setpixel(int x, int y, bool on) {
  if (x < 0 || x > 15) return false;
  if (y < 0 || y > 15) return false;
  // The formulas below depend on how the modules were assembled
  int module_idx = ((x >= 8) ? 1 : 0) + ((y >= 8) ? 0 : 2);
  int module_bit = (x & 7) ^ 7;
  int offset = (y & 7)  * 4 + module_idx;
  bool old = (framebuffer[offset] & (1 << module_bit)) != 0;
  if (on) {
    framebuffer[offset] |= (1 << module_bit);
  } else {
    framebuffer[offset] &= ~(1 << module_bit);
  }
  return old;
}

void display_show_icon(uint16_t icon[DISP_HEIGHT]) {
  display_set_all(false);
  for (int y=0; y<DISP_HEIGHT; y++) {
    uint16_t val = icon[y];
    for (int x=0; x<DISP_WIDTH; x++) {
      if ((val >> x) & 1) {
	display_setpixel(x, y, true);
      }
    }
  }
}


void display_set_all(bool on) {
  memset(framebuffer, on ? 0xff : 0, sizeof(framebuffer));
}

void display_init() {
  // We init SPI bus at the start of display_update function.
  display_update();
}


int display_count_on() {
  int cnt = 0;
  for (size_t i=0; i<sizeof(framebuffer); i++)  {
    cnt += __builtin_popcount(framebuffer[i]);
  }
  return cnt;
}

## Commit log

2023-10-20 initial commit
    Got quad dot drivers working, with a simple demo picture.
2023-10-20 hardware updated
    added support for buttons and encoder
    a very simple demo project
2023-10-20 more hardware changes
    de-energize buttons to enable power off
    split out text to README
    flip the spiral direction
    [display_driver.cpp, t16main.cpp]
2023-10-20 hopefully last hardware changes
    speaker support
    soft power off support
    also adding various duration tuning
2023-10-20 somewhat usable firmware
    can count up or down, depending on timer value
    at start.
    green button is for start/stop time, fully works
    - flashes once per second when ticking
    - blinks continously when time expired
    - on in time set mode
    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
2023-10-20 add related 3d printed models
    [knob-d-shaft-1.scad, knob-d-shaft-1.stl, timer16x16box.scad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]
2023-10-23 Update README
    Also add pre-compiled firmware, just in case.
2023-12-24 Temporarily increase dot interval to 60 seconds
    Also add support for encoder steps less than dot interval.
2024-01-06 Restore dot interval back to 10 second
    Tweak button step more - the original intent was to only modify
    step when dot interval was large, but that's not what I had.
2025-07-04 Add "Shake" mode
    Turning the encode in default (time counting) mode is no longer
    no-op, instead it shakes the dots. Those dots would settle
    automatically in a few seconds.
    [t16main.cpp]
2025-07-04 Rename setpixel -> display_setpixel for consistency
    Also cleanup trailing whitespace
    Also fix a bug where DISPLAY_HEIGHT was 15 by accident
    [display_driver.cpp, t16main.cpp]
2025-07-04 Add basic settings menu, read-only for now
    Change the menu logic flow:
    - When menu is off
    - Blue button enters menu, keeping same item
    - When menu is on
    - Encoder chooses menu item
    - Blue button activates it (cycle values)
    - Green button exits menu
    Include first few icon files based on piskelapp.com,
    as well as piskel->C++ array translator
    Fix display_driver.cpp to ensure X and Y are correct, and (0, 0)
    is in the top-left corner.
    Misc: fix button debounce logic
    [display_driver.cpp, t16main.cpp]

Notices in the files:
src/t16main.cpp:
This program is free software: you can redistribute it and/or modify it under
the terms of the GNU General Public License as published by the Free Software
